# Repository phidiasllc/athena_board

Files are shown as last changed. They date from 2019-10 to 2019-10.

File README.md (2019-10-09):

The Athena Board is a 3-D printer controller board designed to interface with the Orange Pi Zero.

Note pin mappings can differ based upon the definition used by the firmware developer. The pin mapping shown in the spreadsheet is based on the mighty1284p definition; Sanguinololu uses different definitions.

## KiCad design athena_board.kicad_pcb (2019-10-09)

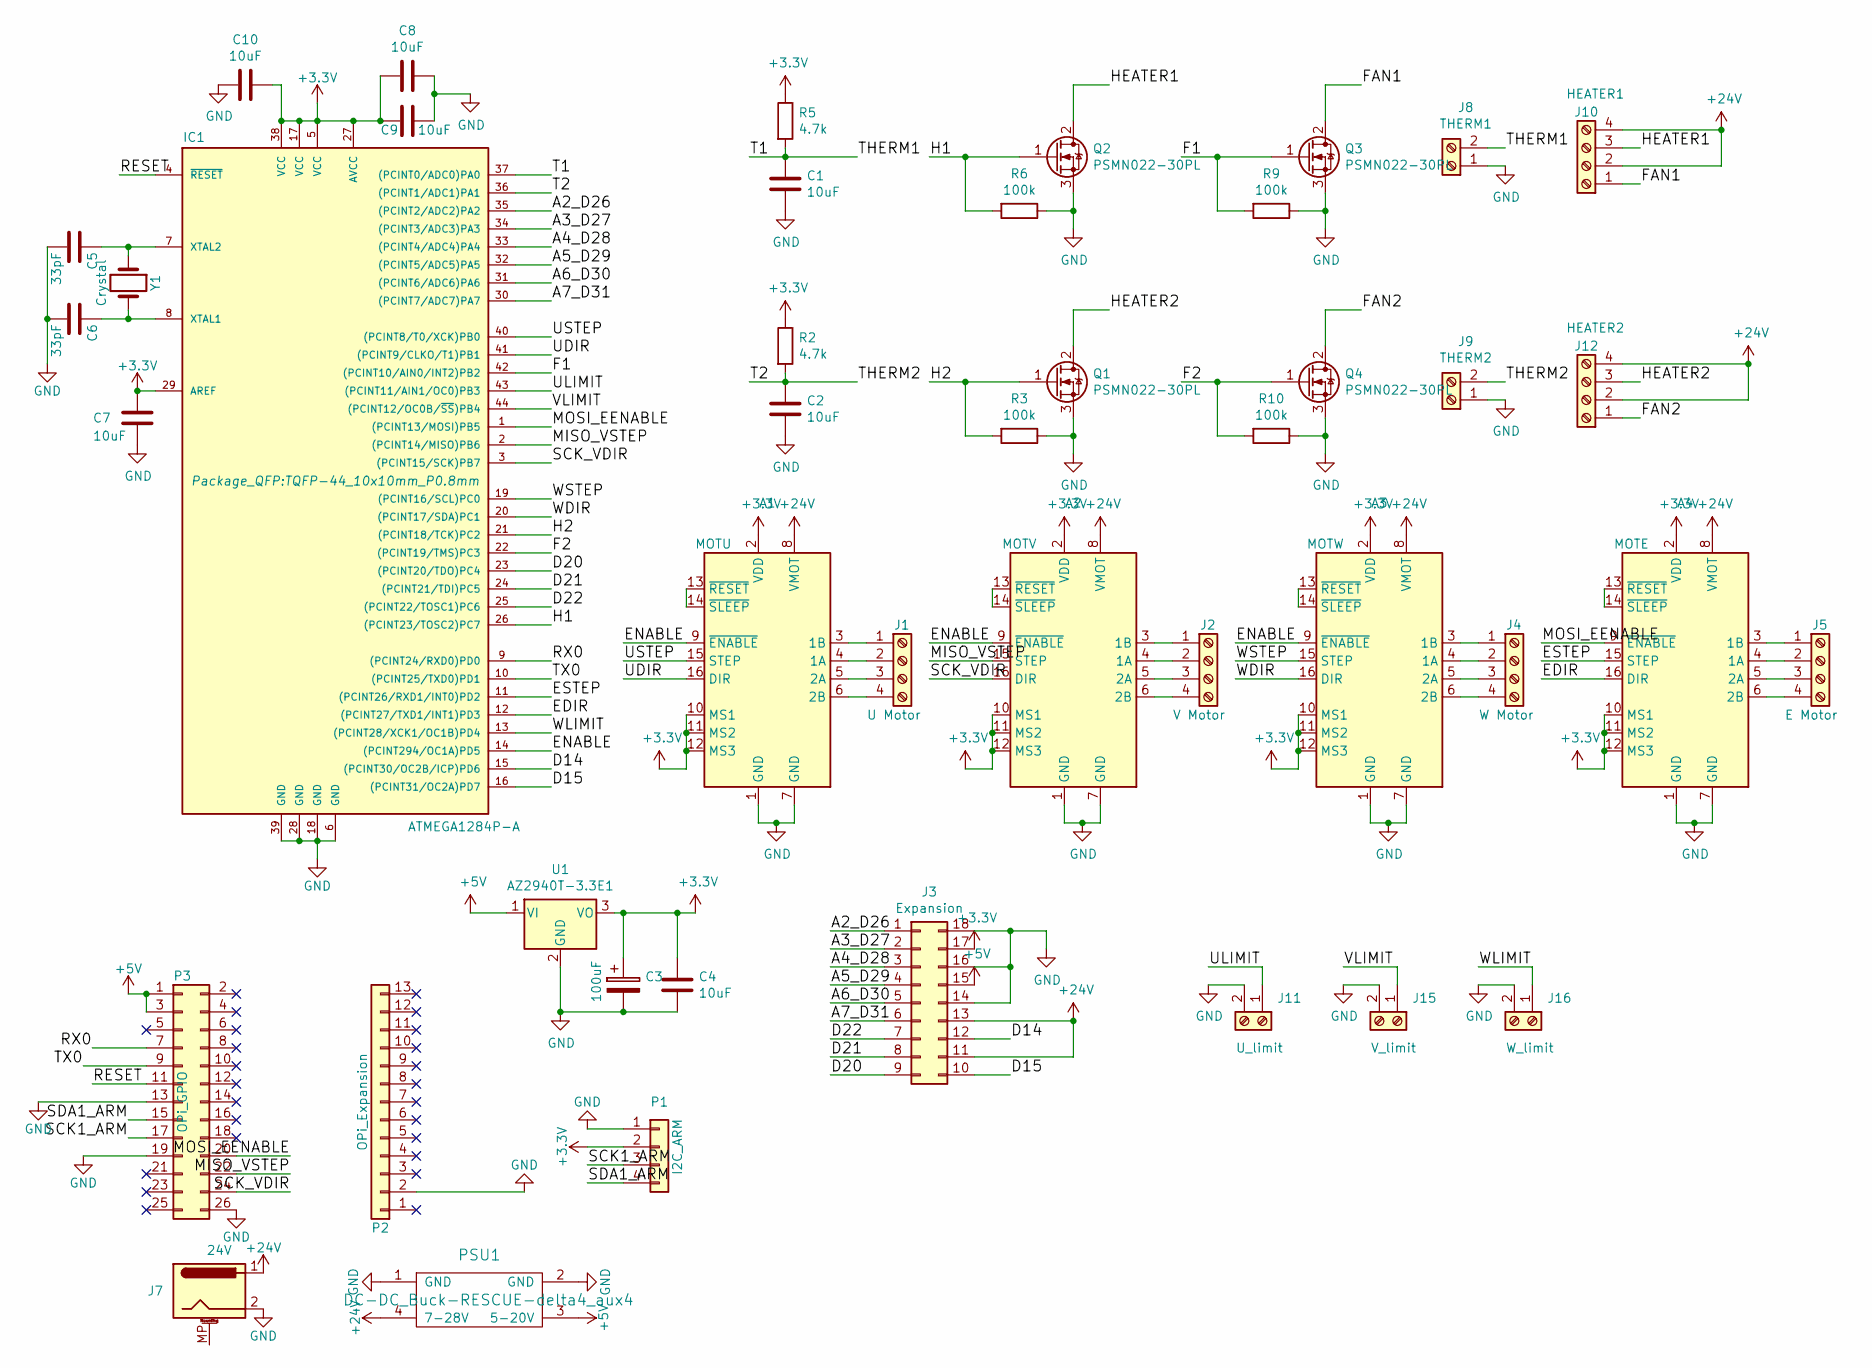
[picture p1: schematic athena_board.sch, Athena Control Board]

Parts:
A1: MOTU; Pololu_Breakout-16_15.2x20.3mm; digikey S7006-ND two required
A2: MOTV; Pololu_Breakout-16_15.2x20.3mm; digikey S7006-ND two required
A3: MOTW; Pololu_Breakout-16_15.2x20.3mm; digikey S7006-ND 2 required
A4: MOTE; Pololu_Breakout-16_15.2x20.3mm; digikey S7006-ND two required
C1, C2, C4, C7, C9, C10: 10uF; C_1206_3216Metric_Pad1.42x1.75mm_HandSolder; digikey 1276-1853-1-ND
C3: 100uF; C_1206_3216Metric_Pad1.42x1.75mm_HandSolder; digikey 478-12404-1-ND
C5, C6: 33pF; C_1206_3216Metric_Pad1.42x1.75mm_HandSolder; digikey 732-7873-1-ND
C8: 10uF; C_1206_3216Metric_Pad1.42x1.75mm_HandSolder
IC1: ATMEGA1284P-A; TQFP-44_10x10mm_P0.8mm; digikey ATMEGA1284P-AU-ND
J1: U Motor; SCREWTERMINAL-3.5MM-4; digikey 277-1860-ND
J2: V Motor; SCREWTERMINAL-3.5MM-4; digikey 277-1860-ND
J3: Expansion; PinSocket_2x09_P2.54mm_Vertical
J4: W Motor; SCREWTERMINAL-3.5MM-4; digikey 277-1860-ND
J5: E Motor; SCREWTERMINAL-3.5MM-4; digikey 277-1860-ND
J7: 24V; BarrelJack_Horizontal
J8: THERM1; SCREWTERMINAL-3.5MM-2; digikey 277-1721-ND
J9: THERM2; SCREWTERMINAL-3.5MM-2; digikey 277-1721-ND
J10: HEATER1; SCREWTERMINAL-5MM-4
J11: U_limit; SCREWTERMINAL-3.5MM-2; digikey 277-1721-ND
J12: HEATER2; SCREWTERMINAL-5MM-4
J15: V_limit; SCREWTERMINAL-3.5MM-2; digikey 277-1721-ND
J16: W_limit; SCREWTERMINAL-3.5MM-2; digikey 277-1721-ND
P1: I2C_ARM; PinHeader_1x04_P2.54mm_Vertical
P2: OPi_Expansion; PinHeader_1x13_P2.54mm_Vertical
P3: OPi_GPIO; PinHeader_2x13_P2.54mm_Vertical
PSU1: DC-DC_Buck-RESCUE-delta4_aux4; 7-28V
Q1, Q2, Q3, Q4: PSMN022-30PL; TO-220-3_Vertical; digikey 1727-5893-ND
R2, R5: 4.7k; R_1206_3216Metric; digikey A130181CT-ND
R3, R6, R9, R10: 100k; R_1206_3216Metric; digikey A129834CT-ND
U1: AZ2940T-3.3E1; TO-220-3_Vertical; digikey AZ2940T-3.3E1DI-ND
Y1: Crystal; Crystal_SMD_HC49-SD; digikey 535-9067-1-ND

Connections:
+3V3: A1.2 (VDD), A1.10 (MS1), A1.11 (MS2), A1.12 (MS3), A2.2 (VDD), A2.10 (MS1), A2.11 (MS2), A2.12 (MS3), A3.2 (VDD), A3.10 (MS1), A3.11 (MS2), A3.12 (MS3), A4.2 (VDD), A4.10 (MS1), A4.11 (MS2), A4.12 (MS3), C3.1, C4.1, C7.1, C8.2, C9.2, C10.2, IC1.5 (VCC), IC1.17 (VCC), IC1.27 (AVCC), IC1.29 (AREF), IC1.38 (VCC), J3.17, P1.2, R2.1, R5.1, U1.3 (VO)
+5V: J3.15, P3.1, P3.3, PSU1.3 (5-20V), U1.1 (VI)
+24V: A1.8 (VMOT), A2.8 (VMOT), A3.8 (VMOT), A4.8 (VMOT), J3.11, J3.13, J7.1, J10.2, J10.4, J12.2, J12.4, PSU1.4 (7-28V)
/A2_D26: IC1.35 ((PCINT2/ADC2)PA2), J3.1
/A3_D27: IC1.34 ((PCINT3/ADC3)PA3), J3.2
/A4_D28: IC1.33 ((PCINT4/ADC4)PA4), J3.3
/A5_D29: IC1.32 ((PCINT5/ADC5)PA5), J3.4
/A6_D30: IC1.31 ((PCINT6/ADC6)PA6), J3.5
/A7_D31: IC1.30 ((PCINT7/ADC7)PA7), J3.6
/D14: IC1.15 ((PCINT30/OC2B/ICP)PD6), J3.12
/D15: IC1.16 ((PCINT31/OC2A)PD7), J3.10
/D20: IC1.23 ((PCINT20/TDO)PC4), J3.9
/D21: IC1.24 ((PCINT21/TDI)PC5), J3.8
/D22: IC1.25 ((PCINT22/TOSC1)PC6), J3.7
/EDIR: A4.16 (DIR), IC1.12 ((PCINT27/TXD1/INT1)PD3)
/ENABLE: A1.9 (~ENABLE), A2.9 (~ENABLE), A3.9 (~ENABLE), IC1.14 ((PCINT294/OC1A)PD5)
/ESTEP: A4.15 (STEP), IC1.11 ((PCINT26/RXD1/INT0)PD2)
/F1: IC1.42 ((PCINT10/AIN0/INT2)PB2), Q3.1 (G), R9.2
/F2: IC1.22 ((PCINT19/TMS)PC3), Q4.1 (G), R10.2
/FAN1: J10.1, Q3.2 (D)
/FAN2: J12.1, Q4.2 (D)
/H1: IC1.26 ((PCINT23/TOSC2)PC7), Q2.1 (G), R6.2
/H2: IC1.21 ((PCINT18/TCK)PC2), Q1.1 (G), R3.2
/HEATER1: J10.3, Q2.2 (D)
/HEATER2: J12.3, Q1.2 (D)
/MISO_VSTEP: A2.15 (STEP), IC1.2 ((PCINT14/MISO)PB6), P3.22
/MOSI_EENABLE: A4.9 (~ENABLE), IC1.1 ((PCINT13/MOSI)PB5), P3.20
/RESET: IC1.4 (~RESET), P3.11
/RX0: IC1.9 ((PCINT24/RXD0)PD0), P3.7
/SCK1_ARM: P1.3, P3.17
/SCK_VDIR: A2.16 (DIR), IC1.3 ((PCINT15/SCK)PB7), P3.24
/SDA1_ARM: P1.4, P3.15
/T1: C1.1, IC1.37 ((PCINT0/ADC0)PA0), J8.2, R5.2
/T2: C2.1, IC1.36 ((PCINT1/ADC1)PA1), J9.2, R2.2
/TX0: IC1.10 ((PCINT25/TXD0)PD1), P3.9
/UDIR: A1.16 (DIR), IC1.41 ((PCINT9/CLKO/T1)PB1)
/ULIMIT: IC1.43 ((PCINT11/AIN1/OC0)PB3), J11.1
/USTEP: A1.15 (STEP), IC1.40 ((PCINT8/T0/XCK)PB0)
/VLIMIT: IC1.44 ((PCINT12/OC0B/~SS~)PB4), J15.1
/WDIR: A3.16 (DIR), IC1.20 ((PCINT17/SDA)PC1)
/WLIMIT: IC1.13 ((PCINT28/XCK1/OC1B)PD4), J16.1
/WSTEP: A3.15 (STEP), IC1.19 ((PCINT16/SCL)PC0)
GND: A1.1 (GND), A1.7 (GND), A2.1 (GND), A2.7 (GND), A3.1 (GND), A3.7 (GND), A4.1 (GND), A4.7 (GND), C1.2, C2.2, C3.2, C4.2, C5.2, C6.2, C7.2, C8.1, C9.1, C10.1, IC1.6 (GND), IC1.18 (GND), IC1.28 (GND), IC1.39 (GND), J3.14, J3.16, J3.18, J7.2, J8.1, J9.1, J11.2, J15.2, J16.2, P1.1, P2.2, P3.13, P3.19, P3.26, PSU1.1 (GND), PSU1.2 (GND), Q1.3 (S), Q2.3 (S), Q3.3 (S), Q4.3 (S), R3.1, R6.1, R9.1, R10.1, U1.2 (GND)
unnamed: A1.3 (1B), J1.1
unnamed: A1.4 (1A), J1.2
unnamed: A1.5 (2A), J1.3
unnamed: A1.6 (2B), J1.4
unnamed: A1.13 (~RESET), A1.14 (~SLEEP)
unnamed: A2.3 (1B), J2.1
unnamed: A2.4 (1A), J2.2
unnamed: A2.5 (2A), J2.3
unnamed: A2.6 (2B), J2.4
unnamed: A2.13 (~RESET), A2.14 (~SLEEP)
unnamed: A3.3 (1B), J4.1
unnamed: A3.4 (1A), J4.2
unnamed: A3.5 (2A), J4.3
unnamed: A3.6 (2B), J4.4
unnamed: A3.13 (~RESET), A3.14 (~SLEEP)
unnamed: A4.3 (1B), J5.1
unnamed: A4.4 (1A), J5.2
unnamed: A4.5 (2A), J5.3
unnamed: A4.6 (2B), J5.4
unnamed: A4.13 (~RESET), A4.14 (~SLEEP)
unnamed: C5.1, IC1.7 (XTAL2), Y1.1
unnamed: C6.1, IC1.8 (XTAL1), Y1.2

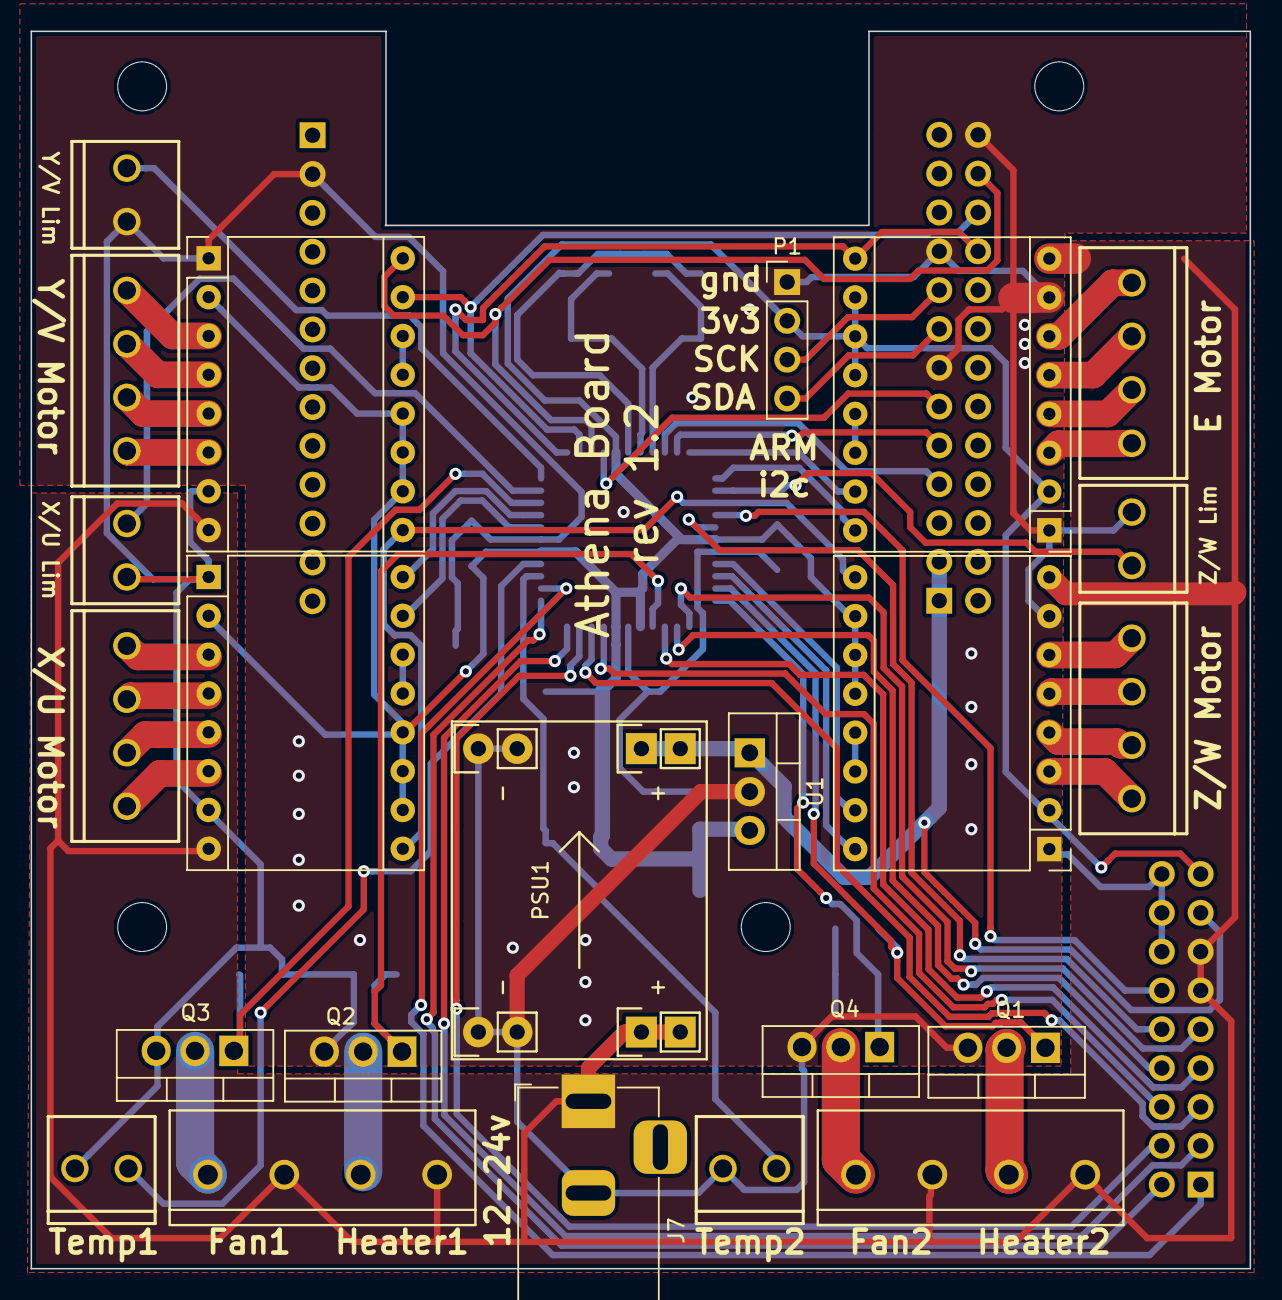
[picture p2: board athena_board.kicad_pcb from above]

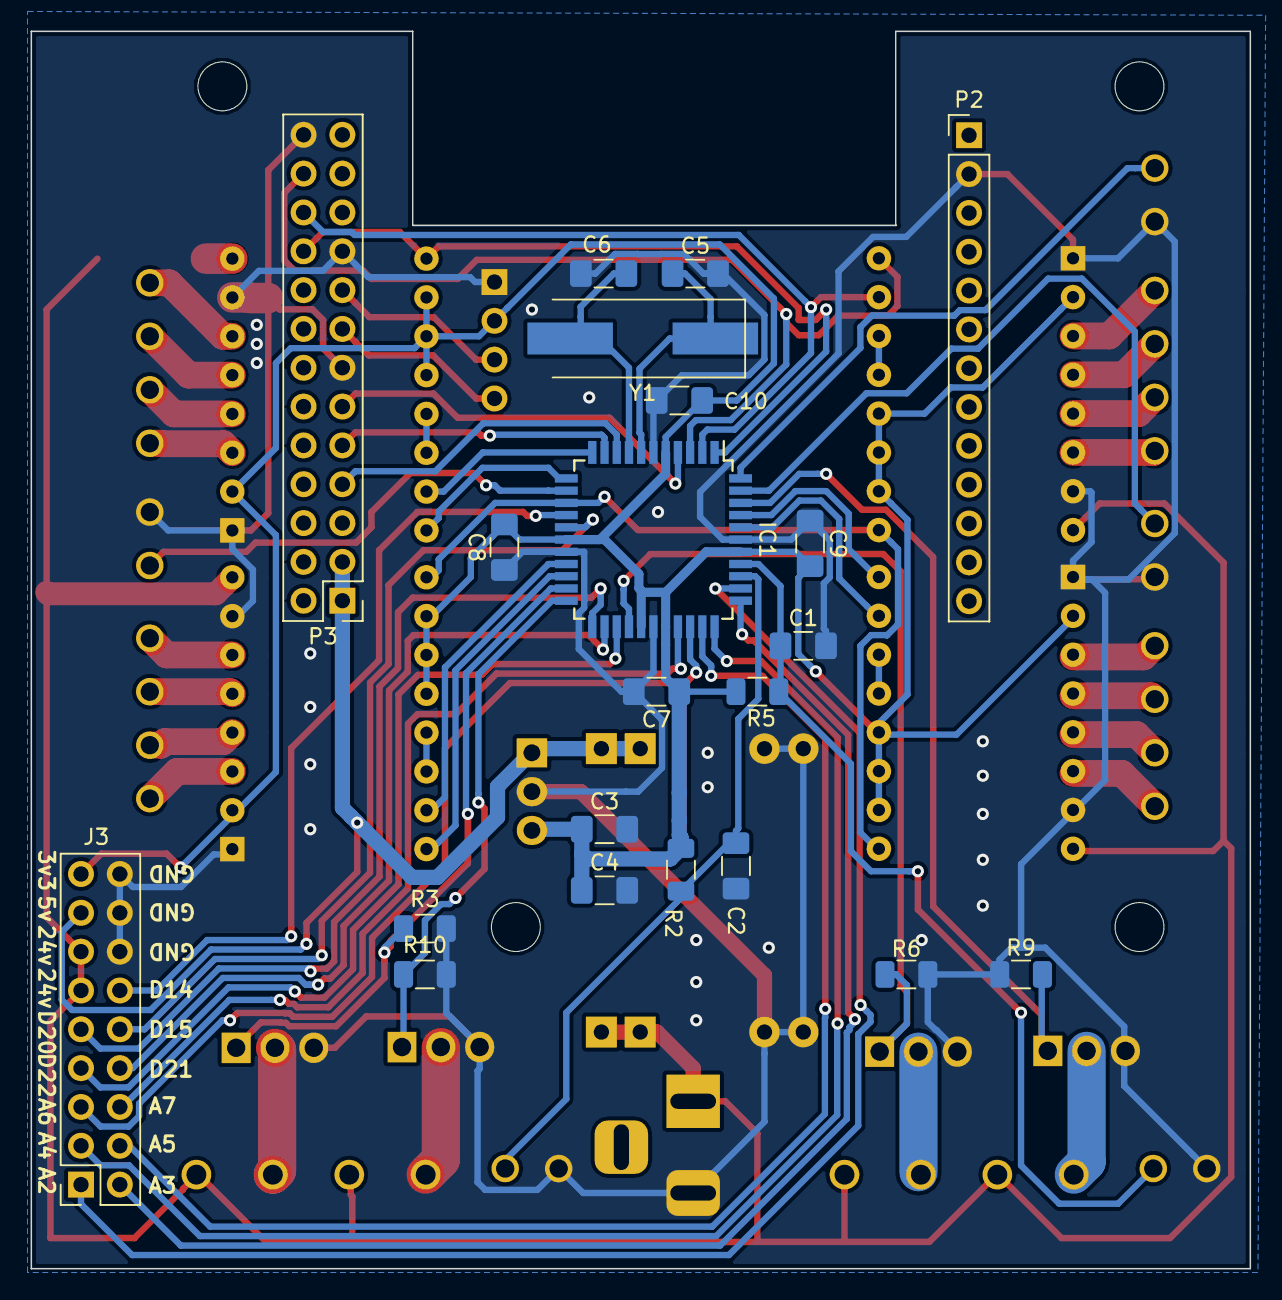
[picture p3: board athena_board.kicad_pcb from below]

Board: 2 copper layers, 79.8 x 81.0 mm, 44 parts (21 on the bottom side), 65 nets.
